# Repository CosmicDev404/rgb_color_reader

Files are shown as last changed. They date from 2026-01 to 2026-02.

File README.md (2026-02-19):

# rgb_color_reader



A low-cost color sensing system using an RGB LED and an LDR, exploring color detection through calibrated illumination and reflected light.
DIY RGB + LDR Color Sensor (Arduino). 

 🔹PCB



🔹Schematic:



#  Description



A low-cost color sensing system using an RGB LED and an LDR.
The idea is to sequentially illuminate a surface with red, green, and blue light and measure reflected intensity to identify colors.
It basically works like a human eye, detecting RGB reflections and determining the surface color.

Cinematic

🔹 Need

Commercial color sensors are expensive and opaque.
This project explores how much can be achieved with basic components, calibration, and software logic.
The fun part is that all the components used are super ubiquitous and affordable, so anyone can make it.

## Components/BOM:

- Arduino (Pro mini)
- An LDR
- Resistors(10kΩ, 2x100Ω & 150Ω)
- An RGB LED with common cathode
- 0.96 inch I2C OLED display
- PCB(gerber included in hardware directory)
- MicroUSB female 5 pin
- 3x6*6*8 push buttons
- 2x12 2.54mm Female Headers + 1x2 2.54mm Female Headers

## Instructions 

- Use the gerber files to create the PCB required for this project from assets
- Upload _"firmware.ino"_ into Arduino pro mini
- Insert Arduino pro mini into the PCB header slots with correct orientation and solder other components
- Make sure that RGB led doesn't directly interfere with LDR readings, ie a separater may be used or correct angles must be ensured
- LDR and RGB must be close to/in contact with the surface for accurate readings

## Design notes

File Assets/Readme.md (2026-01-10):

# hardware/assets
🔹 The schematics and PCB gerber files are located in this directory.

- Yellow means top silk layer
- Red means top copper layer
- Blue means bottom copper layer
- Green means bottom silk layer
- Gray is solder mask



https://github.com/user-attachments/assets/9e0fa189-9529-4978-af45-c62185b296a2

🔹BOM:

- Arduino (Uno or Pro mini) _already owned_
- An LDR
- Resistors(10kΩ, 2x100Ω & 150Ω)
- An RGB LED with common cathode
- 0.96 inch I2C OLED display
- PCB(gerbers included)
- MicroUSB female 5 pin
- 3x6*6*8 push buttons
- 2x12 2.54mm Female Headers + 1x2 2.54mm Female Headers

🔹 Schematic design for the project:



🔹3D render screenshot



🔹Bottom silk screen 

pngtree-vector-space-icon-png-image_4277403

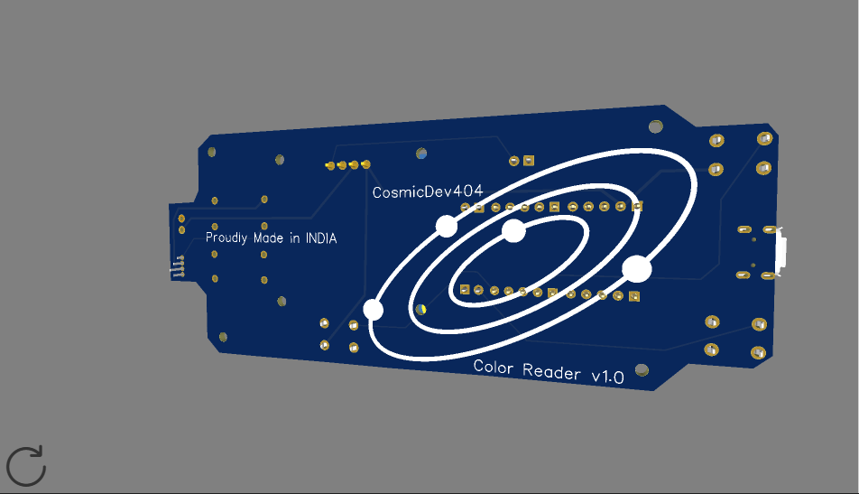
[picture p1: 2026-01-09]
Assets/Screenshot 2026-01-09 142844.png

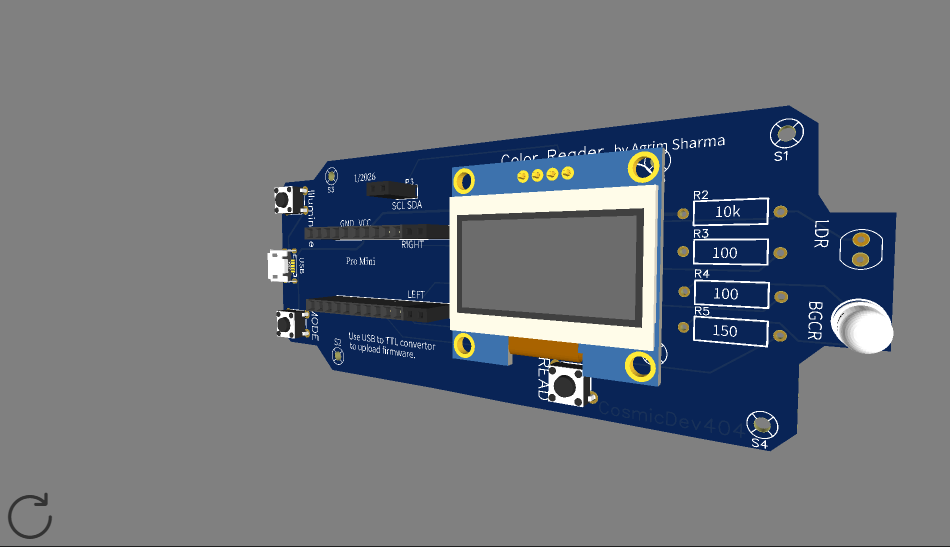
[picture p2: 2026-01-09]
Assets/Screenshot 2026-01-09 142221.png

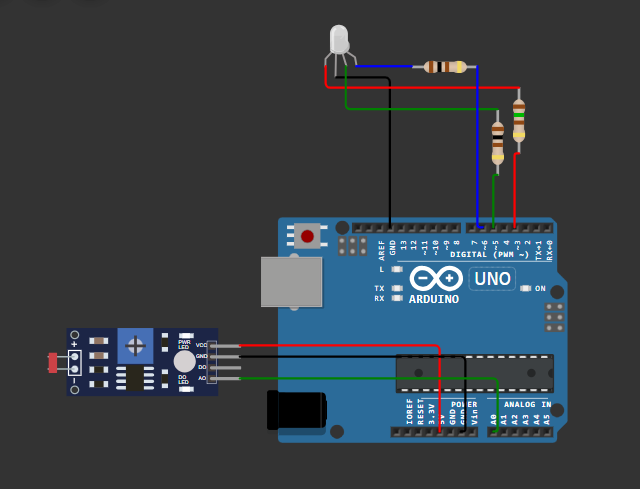
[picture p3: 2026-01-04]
Circuit Diagram.jpg

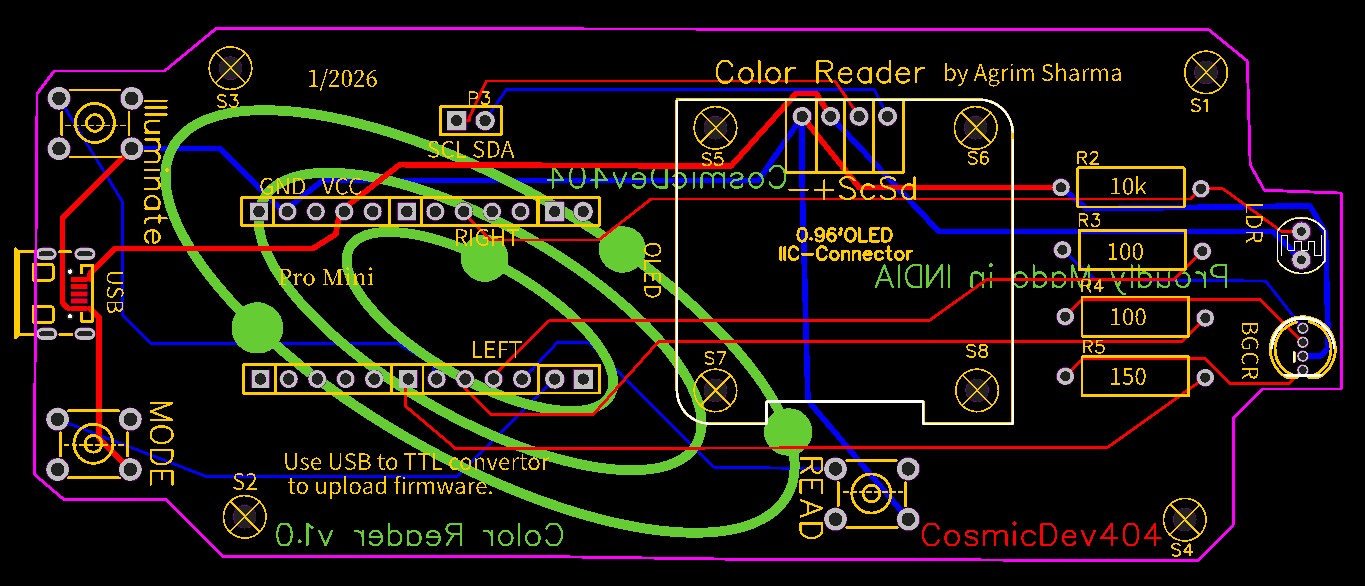
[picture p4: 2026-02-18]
Assets/dig_schem.png

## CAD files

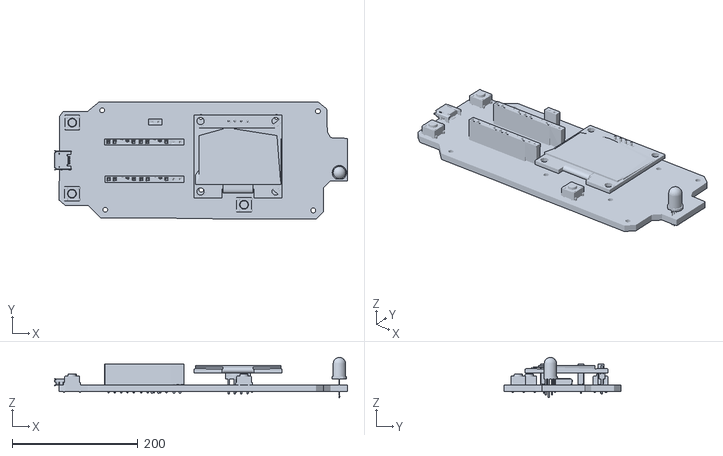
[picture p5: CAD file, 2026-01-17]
Assets/PCB_obj+mtl/OBJ_PCB_Color.obj
465.6 x 186.3 x 63.8

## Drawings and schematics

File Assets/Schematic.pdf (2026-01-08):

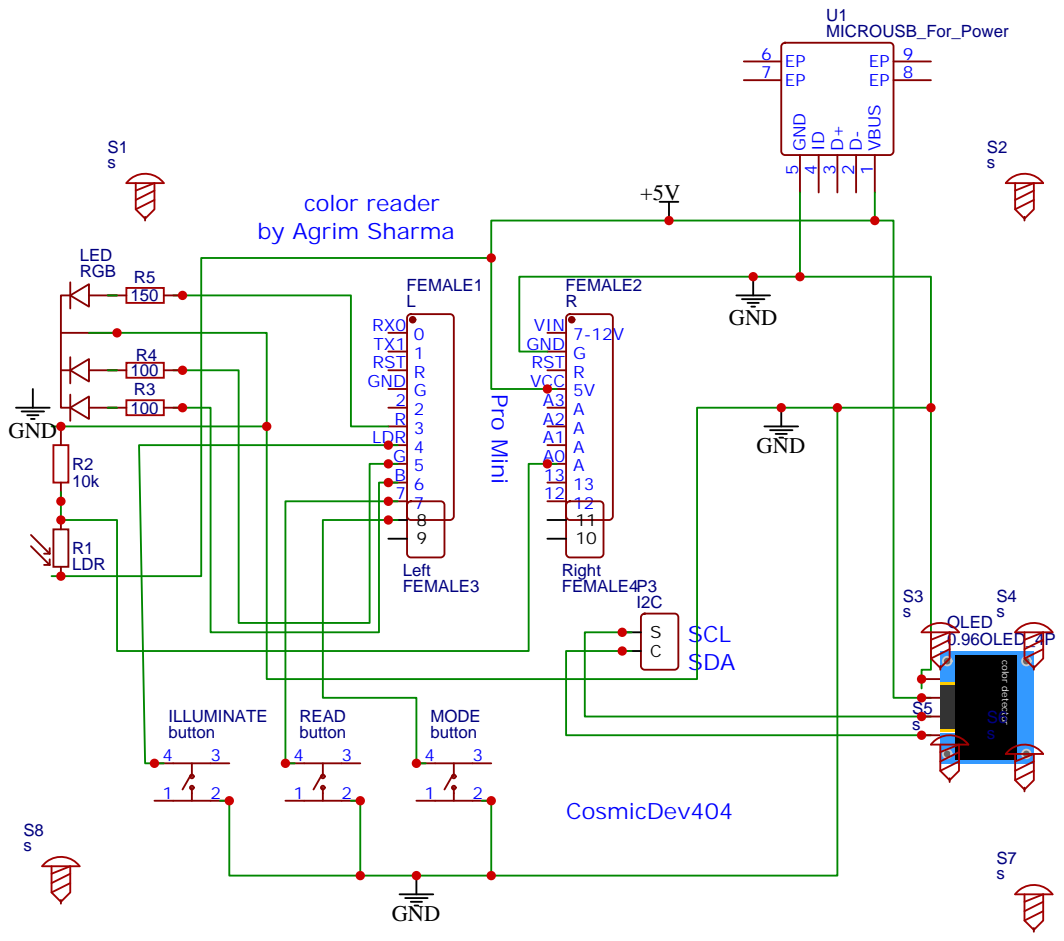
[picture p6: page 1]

Drawn By: Agrim Sharma

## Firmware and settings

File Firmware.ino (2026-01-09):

const int r = 3;
const int g = 5;
const int b = 6;
const int g_i = 200;
const int b_i = 255;
const int r_i = 179;
const int ldr = A0;
const int ill_butt = 4;
int val_R = 0;
int val_G = 0;
int val_B = 0;
int avg[3] = {0,0,0};
bool illuminate = false;
int ill_butt_state = 0;

float minimum;

void setup() {
  pinMode(r, OUTPUT);
  pinMode(g, OUTPUT);
  pinMode(b, OUTPUT);
  pinMode(ldr, INPUT);
  pinMode(ill_butt, INPUT_PULLUP);
  Serial.begin(9600);
}

void loop() {
  if (digitalRead(ill_butt) == LOW){
    if (ill_butt_state == 0){
      ill_butt_state = 1;
    } else if(ill_butt_state == 1){
      ill_butt_state = 0;
    }
    delay(450);
  }
  if (ill_butt_state == 1){
    illuminate = true;
  }else{
    illuminate = false;
  }
  if (illuminate){
    analogWrite(r, r_i);
    analogWrite(g, g_i);
    analogWrite(b, b_i);
  } else{
    processRGB();
    Serial.println(avg[0]); //RED
    Serial.println(avg[1]); //GREEN
    Serial.println(avg[2]); //BLUE
    Serial.println(color_mapper(0, int(avg[0]), int(avg[1]), int(avg[2])));  //color name
    Serial.println(minimum); 
    Serial.println(color_mapper(1, int(avg[0]), int(avg[1]), int(avg[2])));  //color name
    Serial.println(minimum);
  }  
}

void emit(int color, int intensity, int &val){  //just emits each color and read the LDR values
  analogWrite(color, intensity);
  delay(50);
  val = analogRead(ldr);
  analogWrite(color, 0);
  delay(50);
}

void sample(){  //emits and store the readings for RGB
  emit(r, r_i, val_R);
  emit(g, g_i, val_G);
  emit(b, b_i, val_B);
}

void processRGB(){  //normalizes RGB readings and maps them to same intensity for further processing
  int RED = 0;
  int GREEN = 0;
  int BLUE = 0;
  for(int i = 0; i<5; i++){
    sample();
    RED = val_R + RED;
    GREEN = val_G + GREEN;
    BLUE = val_B + BLUE;
  }
  RED = RED / 5;
  GREEN = GREEN / 5;
  BLUE = BLUE/ 5;
  int RED_norm = map(RED, 0, 467, 0, 255);  //fine tuned by from the reflection of a white surface
  int GREEN_norm = map(GREEN, 0, 229, 0, 255);  //fine tuned by from the reflection of a white surface
  int BLUE_norm = map(BLUE, 0, 195, 0, 255);  //fine tuned by from the reflection of a white surface
  avg[0] = RED_norm;
  avg[1] = GREEN_norm;
  avg[2] = BLUE_norm;
}

char* color_mapper(int mode, int R, int G, int B) { //passes color names for inputted RGB codes
  static char color[50];
  //float minimum;
  float red;
  float green;
  float blue;
  float cyan;
  float magenta;
  float yellow;
  float orange;
  float kesari; //the Indian Saffron
  float Lgreen;
  float saffron;
  float pink;
  float wheat;
  float gold;
  float turquoise;
  float white;
  float gray;
  float teal;
  float brown;
  float plotR[3] = {255-R, G, B};
  avg_arr(plotR, red);
  float plotG[3] = {R, 255-G, B};
  avg_arr(plotG, green);
  float plotB[3] = {R, G, 255-B};
  avg_arr(plotB, blue);
  float plotC[3] = {R, 255-G, 255-B};
  avg_arr(plotC, cyan);
  float plotM[3] = {255-R, G, 255-B};
  avg_arr(plotM, magenta);
  float plotY[3] = {255-R, 255-G, B};
  avg_arr(plotY, yellow);
  float plotO[3] = {255-R, abs(165-G), B};
  avg_arr(plotO, orange);
  float plotK[3] = {255-R, abs(119-G), abs(34-B)};
  avg_arr(plotK, kesari);
  float plotLG[3] = {abs(50-R), abs(205-G), abs(50-B)};
  avg_arr(plotLG, Lgreen);
  float plotSaffron[3] = {abs(255-R), abs(183-G), abs(206-B)};
  avg_arr(plotSaffron, saffron);
  float plotpink[3] = {abs(251-R), abs(116-G), abs(168-B)};
  avg_arr(plotpink, pink);
  float plotwheat[3] = {abs(245-R), abs(222-G), abs(179-B)};
  avg_arr(plotwheat, wheat);
  float plotgold[3] = {abs(229-R), abs(184-G), abs(11-B)};
  avg_arr(plotgold, gold);
  float plottur[3] = {abs(4-R), abs(255-G), abs(247-B)};
  avg_arr(plottur, turquoise);
  float plotwhite[3] = {abs(255-R), abs(255-G), abs(255-B)};
  avg_arr(plotwhite, white);
  float plotgray[3] = {abs(128-R), abs(128-G), abs(128-B)};
  avg_arr(plotgray, gray);
  float plotteal[3] = {R, abs(128-G), abs(128-B)};
  avg_arr(plotteal, teal);
  float plotbrown[3] = {abs(143-R), abs(98-G), abs(81-B)};
  avg_arr(plotbrown, brown);

  if (mode==0){
    float val_array[6]= {red, blue, green, cyan, magenta, yellow};
    min_finder(val_array, 6, minimum);
  }
  if (mode==1){
    float val_array[12]= {orange, kesari, Lgreen, saffron, pink, wheat, gold, turquoise, white, gray, teal, brown};
    min_finder(val_array, 12, minimum);
  }


  if(minimum==cyan){  // CMY
    strcpy(color, "Cyan");
  }else if(minimum==magenta){
    strcpy(color, "Magenta");
  }else if(minimum==yellow){
    strcpy(color, "Yellow");
  }else if(minimum==red){ //RGB
    strcpy(color, "Red");
  }else if(minimum==green){
    strcpy(color, "Green");
  }else if(minimum==blue){
    strcpy(color, "Blue");
  }else if(minimum==orange){  //tirtiary colors and others
    strcpy(color, "Orange");
  }else if(minimum==kesari){
    strcpy(color, "Kesari");
  }else if(minimum==Lgreen){
    strcpy(color, "Lime Green");
  }else if(minimum==saffron){
    strcpy(color, "Saffron");
  }else if(minimum==pink){
    strcpy(color, "Pink");
  }else if(minimum==wheat){
    strcpy(color, "Wheat");
  }else if(minimum==gold){
    strcpy(color, "Gold");
  }else if(minimum==turquoise){
    strcpy(color, "Turquoise");
  }else if(minimum==white){ //neutrals
    strcpy(color, "White");
  }else if(minimum==gray){
    strcpy(color, "Gray");
  }else if(minimum==teal){
    strcpy(color, "Teal");
  }else if(minimum==brown){
    strcpy(color, "Brown");
  }else{strcpy(color, "!error!");}  //can only occur when logic fails silently
  return color;
}

int avg_arr(float array_to_be_averaged[], float &avg_found){  //makes the average value for the color inputted
  avg_found=0;
  for(int j = 0; j<3; j++){
    avg_found+=array_to_be_averaged[j];
  }
  avg_found=avg_found/3;
  return avg_found;
}
int min_finder(float ARRAY[], int size, float &smallest){ //finds the minimum value stored in input array
  smallest=255;
  for(int k = 0; k<size; k++){
    if(ARRAY[k]<smallest){
      smallest=ARRAY[k];
    }
  }
  return smallest;  
}

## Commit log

2026-01-03 RGB LED calibration
    This is the basic driver on Arduino Uno to emit RGB LED light with balanced brightness. Next step includes getting inputs and sensing.
2026-01-04 Add RGB LDR calibration functionality
    Added LDR, reading normalisation and averaging
2026-01-04 #circuit 2
2026-01-06 Current Circuit Diagram
2026-01-06 Current Circuit
2026-01-08 Hardware documentation
    Added information about schematics and PCB layers.
2026-01-08 Update Readme with schematic and silk screen images
2026-01-08 Add RGB LED control functionality
2026-01-08 Gerber file for pcb
2026-01-08 Added BOM
    [BOM_Color_2026-01-08.csv]
2026-01-08 Changes in PCB
    [BOM_Color_2026-01-08.csv]
2026-01-09 Update README with BOM and PCB details
    Added a bill of materials (BOM) and PCB images to the README. Removed redundant parts list.
2026-01-09 Added BOM, PCB and schematic details
2026-01-09 Updated structure
    [BOM_Color_2026-01-08 (1).csv]
2026-01-09 Add BOM to Hardware README
    Added a Bill of Materials (BOM) for the hardware project.
2026-01-09 STEP CAD file of this project's PCB
2026-01-09 Interactive BOM with 3D PCB layout
2026-01-10 Added CAD
2026-01-17 OBJ files
    [OBJ_PCB_Color.obj]
2026-01-17 OBJ files added
    [OBJ_PCB_Color.obj]
2026-01-17 Gerber files
    [Drill_NPTH_Through.DRL, Drill_PTH_Through.DRL, Drill_PTH_Through_Via.DRL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]
2026-01-17 Gerber files unzipped
    [Drill_NPTH_Through.DRL, Drill_PTH_Through.DRL, Drill_PTH_Through_Via.DRL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]
2026-02-18 Digital Circuit Diagram for PCB
